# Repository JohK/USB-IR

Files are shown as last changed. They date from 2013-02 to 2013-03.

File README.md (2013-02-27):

Software
========
This software includes the firmware for a usb-to-IR sender dongle, the host cli interface for windows and linux and a labview programm for sending IR commands.

Other Software
==============
vusb
----
This package makes use of v-usb for avr, which can be used in the terms of GPL v2.

IRMP
----
IRMP is a package by Frank M. from the http://www.mikrocontroller.net/ web-board. The header also states a GPL license, a svn repository is over at mikrocontroller.net.

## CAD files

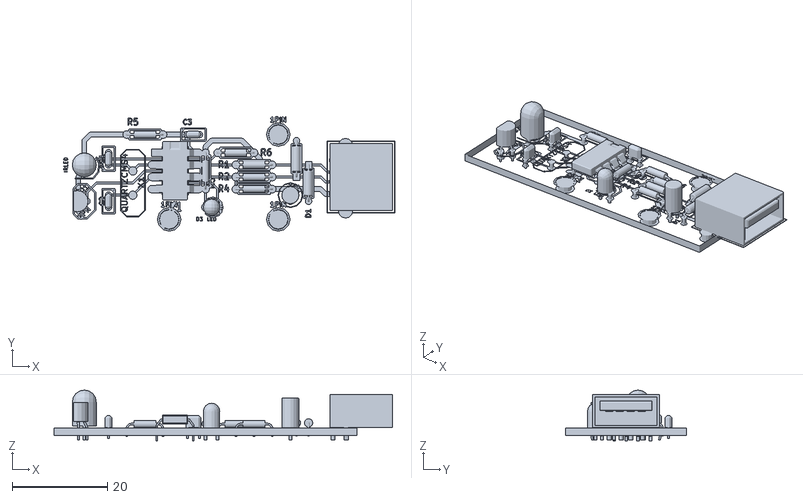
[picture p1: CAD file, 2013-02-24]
board/irusb.stl
71.4 x 25.4 x 10.7

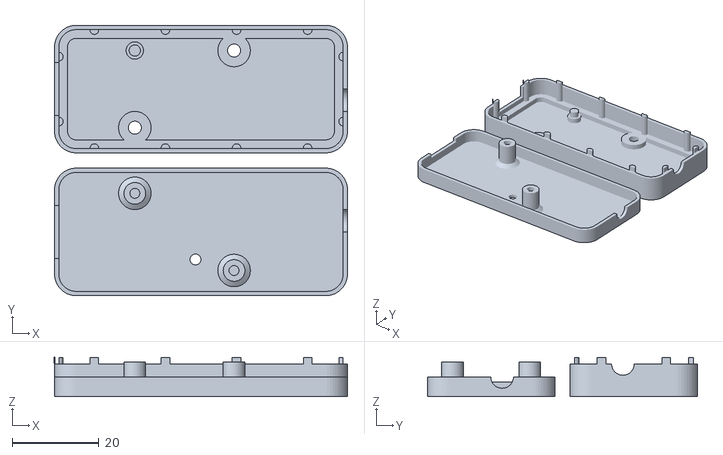
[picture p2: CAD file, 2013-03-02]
enclosing/irusb-enclosing.stl
67.5 x 62.3 x 9.00

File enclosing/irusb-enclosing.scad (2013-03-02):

$fn=50;

dim_brd = [63.5, 25.4, 10];
brd_thickness = 1.5;

brd_width = 25.4;
brd_length = 63.5;
brd_height = 10;

wall = 1;
wallv = [1,1,1];
cl_wall = 1;

o_width = brd_width+2*wall+2*cl_wall;
o_length = brd_length+2*wall+2*cl_wall;
o_height = brd_height+2*wall;

dimo = [o_length, o_width, o_height];
o_cornrad = 5;

// screw 1 x:-16.51  y: 3.81
pos_screw1 = [16.5, 21.59, 0];
// screw 2 x:-39.37  y: 3.81
pos_screw2 = [39.37, 21.59, 0];
// screw 3 x:-16.51  y:21.59
pos_screw3 = [16.51, 3.81, 0];

pos_irled = [dim_brd[0]+2*wallv[0]+0.5, 10.16, 5];
dia_irled = 5;
//y_irled = 15.24;
//z_irled = 7.5;

pos_sled = [30.48, 19.05, dim_brd[2]-2*wallv[2]];
dia_sled = 2;
//x_sled = -30.48;
//y_sled = 6.35;

pos_usb = [-3*wallv[0], dim_brd[1]/2, brd_thickness];
//y_usb = brd_width/2;


// include <nutsnbolts/cyl_head_bolt.scad>;


// board();


translate([0,0,wallv[2]+brd_thickness])  // manufact. offset

// bottom half
difference() {
	union() {
	//color("Grey", 0.2)
		case_rounded(dimo=dimo, wall=wallv, ch=7.5, cl=[2,2,1.5], r=o_cornrad, bottom=true, center=false);
	translate(pos_screw1) mountpost(ro = 2, ho = 1.5, ri = 1.5, hi = 1.75, cl_ri=0.2);

	translate(pos_screw2-[0,0,1.5]) cylinder(r=3.75,h=1.5);
	translate(pos_screw3-[0,0,1.5]) cylinder(r=3.75,h=1.5);
	}

	openings();
	translate(pos_screw2-[0,0,1.75])
		union() {
			cylinder(r=1.5,h=15,center=true);
			cylinder(r=2.75,h=2,center=true);
		}
	translate(pos_screw3-[0,0,1.75])
		union() {
			cylinder(r=1.5,h=15,center=true);
			cylinder(r=2.75,h=2,center=true);
		}


//translate([16.51,-50,-20]) cube([200,200,200]);
}


// upper half
 translate([0,-7.5,dimo[2]-wallv[2]-brd_thickness]) rotate ([180,0,0])
		
	difference(){
	union() {
		case_rounded(dimo=dimo, wall=wallv, ch=7.5, cl=[2,2,1.5], r=o_cornrad, bottom=false, center=false);
		for (pos_screw = [pos_screw2, pos_screw3]) {
			translate([0,0,dimo[2]-wallv[2]-cl_wall-brd_thickness]+pos_screw)
				rotate([180,0,0]) screwpost(do=5,di=2.3,h=7);
		}
	}

	openings();
	//translate(pos_screw2) cube(dimo);
}

module openings() {
	// ir-LED hole
	translate(pos_irled) rotate([0, -90, 0]) hole_led(d=dia_irled);
	// status LED hole
	translate(pos_sled) hole_led(d=2, cld=0.5);
	// usbA
	translate(pos_usb) hole_usbAm();
}













module case_rounded(
	dimo, // outer dimensions (vector)
	wall, // wall thicknesses (vector)
	r,    // corner radius
	ch,   // cut height (bottom, top)
	cl=[0.2, 0.2, 1], // board clearance
	bottom=true,
	center=true
 	) {

	translate(center ? [0,0,0] : dimo/2-wall-cl/2-[0,0,cl[2]/2])

	union() {

	difference(){
	union() {
		difference(){
			cube_rounded(dim=dimo,r=r,center=true);
			cube_rounded(dim=dimo-2*wall,r=r-wall[0],center=true);

			//translate([0,0,6]) cube([250,250,10], center=true);
		}

	// bevel
		translate([0,0,-dimo[2]/2+wall[2]+cl[2]/2])
		difference(){
			cube_rounded(dim=[dimo[0], dimo[1], cl[2]], r=r, center=true);
			assign(tmp = [dimo[0]-2*wall[0]-2*cl[0], dimo[1]-2*wall[1]-2*cl[1], cl[2]+0.1])
				cube_rounded(dim=tmp,r=r-wall[0]-cl[0],center=true);
		}
	} // end of union (basebody)

	translate(bottom ? [0,0, ch] : 
			            [0,0, -dimo[2]+ch])
		cube(dimo, center=true);
	}

	if (bottom) {
	// alignment
	difference() {
		for (i = [[-0.75, 1], [-0.25, 1], [0.25, 1], [0.75, 1],
                 [-0.75, -1], [-0.25, -1], [0.25, -1], [0.75, -1],
				  [-1, 0.55], [-1, -0.55],
                 [1, 0.55], [1, -0.55]]) {
			translate([i[0]*(dimo[0]/2-wall[0]),i[1]*(dimo[1]/2-wall[0]-0.1),-dimo[2]/2])
           		cylinder(d=wall[0],h=ch+1.5,center=false);
		}
			difference(){
			cube_rounded(dim=dimo,r=r,center=true);
			cube_rounded(dim=dimo-2*wall,r=r-wall[0],center=true);
		}
	}
	} // end if

	}
}







module mountpost( 
				   ro = 5,       // outer radius
                  ho = 1.5,     // height of post
                  ri = 3,       // radius of inner radius (that goes through mounting hole in pcb)
                  hi = 1.5,     // height of cyl that goes through mounting hole
                  cl_ri=0.2     // clearance for inner radius
                ) {
	translate([0, 0, -ho/2]) cylinder(r=ro, h=ho, center=true);
	translate([0, 0, hi/2]) cylinder(r=ri-cl_ri, h=hi, center=true);
	
}

module screwpost(
	di = 2.3,
	do = 5,
	h = 5,
	) {
	translate([0,0, h/2])
	difference() {
		union() {
			translate([0,0,-h/2+0.5]) cylinder(r1=do*.75, r2=do/2, h=1, center=true);
			cylinder(r=do/2,h=h,center=true); }
		cylinder(r=di/2,h=h+0.1,center=true);
	


	}
}


module board() {
	translate([0, brd_width, 0]) rotate([0, 0, 180]) 
	union() {
		color("DarkGreen") translate([-brd_length, 0, 0]) cube([brd_length, brd_width, 1.5]);
		translate([-24.75, 0, 0.7]) import_stl("../board/irusb.stl");
	}
}

module hole_led(d=5, h=5, cld=0.2) {
	translate([0,0, h/2]) cylinder(r=d/2+cld/2, h=h, center=true);
}

module hole_usbAm(l=15, clw=0.2, clh=0.2) {
	translate([l/2,0,(4.5+clh)/2]) cube([l,12+clw,4.5+clh], center=true);
}





module cube_rounded(
				dim=[1,1,1],  // dimension of "cube"
				r=0.5,          // radius of rounded corner (xy)
				center=false  // is centered?
					) {
	translate(center ? [0,0,0] : [dim[0]/2,dim[1]/2,0])
	hull() for(m=[[0,0,0], [1,0,0], [dim[0]-r*2,dim[1]-r*2,0], [0,1,0]])
		mirror(m) translate([dim[0]/2-r, dim[1]/2-r, 0]) cylinder(h=dim[2],r=r, center=center);
}


module square_rounded(l=60,w=25,h=10,r=5, center=false) {
	translate(center ? [0,0,0] : [l/2,w/2,0])
	hull() for(m=[[0,0,0], [1,0,0], [l-r*2,w-r*2,0], [0,1,0]])
		mirror(m) translate([l/2-r, w/2-r, 0]) cylinder(h=h,r=r, center=center);
}

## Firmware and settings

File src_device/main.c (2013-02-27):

/* Name: main.c
 * Project: hid-data, example how to use HID for data transfer
 * Author: Christian Starkjohann
 * Creation Date: 2008-04-11
 * Tabsize: 4
 * Copyright: (c) 2008 by OBJECTIVE DEVELOPMENT Software GmbH
 * License: GNU GPL v2 (see License.txt), GNU GPL v3 or proprietary (CommercialLicense.txt)
 * This Revision: $Id$
 */

/* PIN Configuration on Atmega 8
 *
 * Status LED:  PB0 (PIN14)
 * USB D-:		PD2 (PIN2)   // D-/D+ reversed for the usbSofCount feature
 * USB D+:		PD0 (PIN4)
 *
 */

/* PIN Configuration on ATtiny45
 # IR LED:	PB0 (PIN 5)
 # USB D-:  PB1 (PIN 6)
 # USB D+:  PB2 (PIN 7) 
*/

/*
This example should run on most AVRs with only little changes. No special
hardware resources except INT0 are used. You may have to change usbconfig.h for
different I/O pins for USB. Please note that USB D+ must be the INT0 pin, or
at least be connected to INT0 as well.
*/

#include <avr/io.h>
#include <avr/wdt.h>
#include <avr/interrupt.h>  /* for sei() */
#include <util/delay.h>     /* for _delay_ms() */
#include <avr/eeprom.h>

#include <avr/pgmspace.h>   /* required by usbdrv.h */
#include "usbdrv.h"
#include "oddebug.h"        /* This is also an example for using debug macros */

#include "irsnd.h"			/* IR Library */

/* ------------------------------------------------------------------------- */
/* ----------------------------- USB interface ----------------------------- */
/* ------------------------------------------------------------------------- */

PROGMEM const char usbHidReportDescriptor[22] = {    /* USB report descriptor */
    0x06, 0x00, 0xff,              // USAGE_PAGE (Generic Desktop)
    0x09, 0x01,                    // USAGE (Vendor Usage 1)
    0xa1, 0x01,                    // COLLECTION (Application)
    0x15, 0x00,                    //   LOGICAL_MINIMUM (0)
    0x26, 0xff, 0x00,              //   LOGICAL_MAXIMUM (255)
    0x75, 0x08,                    //   REPORT_SIZE (8)
    0x95, 0x06,                    //   REPORT_COUNT (6)
    0x09, 0x00,                    //   USAGE (Undefined)
    0xb2, 0x02, 0x01,              //   FEATURE (Data,Var,Abs,Buf)
    0xc0                           // END_COLLECTION
};


/* Since we define only one feature report, we don't use report-IDs (which
 * would be the first byte of the report). The entire report consists of 128
 * opaque data bytes.
 */

/* The following variables store the status of the current data transfer */
static uchar    currentAddress;
static uchar    bytesRemaining;

static uchar	buf[6];

static uchar	flag_send;



/* ------------------------------------------------------------------------- */

/* usbFunctionRead() is called when the host requests a chunk of data from
 * the device. For more information see the documentation in usbdrv/usbdrv.h.
 */
uchar   usbFunctionRead(uchar *data, uchar len)
{
    if(len > bytesRemaining)
        len = bytesRemaining;
    //eeprom_read_block(data, (uchar *)0 + currentAddress, len);

	//memcpy(data, &buf[currentAddress], len);
	*data = &buf;
    currentAddress += len;
    bytesRemaining -= len;
	flag_send = 1;
    return len;
}

/* usbFunctionWrite() is called when the host sends a chunk of data to the
 * device. For more information see the documentation in usbdrv/usbdrv.h.
 */
uchar   usbFunctionWrite(uchar *data, uchar len)
{
    if(bytesRemaining == 0)
        return 1;               /* end of transfer */
    if(len > bytesRemaining)
        len = bytesRemaining;
    //eeprom_write_block(data, (uchar *)0 + currentAddress, len);
	memcpy(&buf[currentAddress], data, len);
    currentAddress += len;
    bytesRemaining -= len;
	flag_send = 1;
    return bytesRemaining == 0; /* return 1 if this was the last chunk */
}

/* ------------------------------------------------------------------------- */

usbMsgLen_t usbFunctionSetup(uchar data[8])
{
usbRequest_t    *rq = (void *)data;

    if((rq->bmRequestType & USBRQ_TYPE_MASK) == USBRQ_TYPE_CLASS){    /* HID class request */
        if(rq->bRequest == USBRQ_HID_GET_REPORT){  /* wValue: ReportType (highbyte), ReportID (lowbyte) */
            /* since we have only one report type, we can ignore the report-ID */
            bytesRemaining = 6;
            currentAddress = 0;
            return USB_NO_MSG;  /* use usbFunctionRead() to obtain data */
        }else if(rq->bRequest == USBRQ_HID_SET_REPORT){
            /* since we have only one report type, we can ignore the report-ID */
            bytesRemaining = 6;
            currentAddress = 0;
            return USB_NO_MSG;  /* use usbFunctionWrite() to receive data from host */
        }
    }else{
        /* ignore vendor type requests, we don't use any */
    }
    return 0;
}

/* ------------------------------------------------------------------------- */

/*// start status LED, t blinking period in 
void statusLed_Start (uchar t)
{
	if (!Led_T) {
		Led_C = t;
		PORTB |= 0x01;	// LED off
	}
  Led_T = Led_F = t;
}

// LED-state  tested every 1 ms (SOF)
static void statusLed_On1ms(void) {
	uchar led_t = Led_T, led_c;
	if (!led_t) return;
		led_c = Led_C;			// load to register
	if (!--led_c) {
		PORTB ^= 0x01;			// toggle LED
		led_c = Led_F;			// reload counter
	}
 	if (!--led_t) PORTC &= ~0x01;	// switch LED on 
	Led_T = led_t;				// write back register
	Led_C = led_c;
}
*/


void timer1_init (void)
{
//#if defined (__AVR_ATtiny45__) || defined (__AVR_ATtiny85__)                // ATtiny45 / ATtiny85:
	
	// this is 266 ... for a 8bit timer this is too high
    //OCR1C   =  (F_CPU / F_INTERRUPTS / 4) - 1;                              // compare value: 1/15000 of CPU frequency, presc = 4
	OCR1C = 255;
    TCCR1   = (1 << CTC1) | (1 << CS11) | (1 << CS10);                      // switch CTC Mode on, set prescaler to 4
//#else                                                                       // ATmegaXX:
//    OCR1A   =  (F_CPU / F_INTERRUPTS) - 1;                                  // compare value: 1/15000 of CPU frequency
//    TCCR1B  = (1 << WGM12) | (1 << CS10);                                   // switch CTC Mode on, set prescaler to 1
//#endif

#ifdef TIMSK1
    TIMSK1  = 1 << OCIE1A;                                                  // OCIE1A: Interrupt by timer compare
#else
    TIMSK   = 1 << OCIE1A;                                                  // OCIE1A: Interrupt by timer compare
#endif
}



/*---------------------------------------------------------------------------------------------------------------------------------------------------
 *  * timer 1 compare handler, called every 1/10000 sec
 *   *---------------------------------------------------------------------------------------------------------------------------------------------------
 *    */
#if defined (__AVR_ATtiny45__) || defined (__AVR_ATtiny85__)                // ATtiny45 / ATtiny85:
	ISR(TIM1_COMPA_vect, ISR_NOBLOCK)
#else
	ISR(TIMER1_COMPA_vect, ISR_NOBLOCK)
#endif
{
	    (void) irsnd_ISR();                                                     // call irsnd ISR

		// call other timer interrupt routines here...
}



/* ------------------------------------------------------------------------- */

int main(void)
{
	//DDRB &= ~((1 << DDB1) | (1 << DDB2));
	//DDRB  = 0x01;
	//PORTB |= (1<<PB0); // LED IRLED debug
	uchar   i;
	//uchar SofCmp = 0;

	IRMP_DATA *irmp_data;

    wdt_enable(WDTO_1S);
    /* Even if you don't use the watchdog, turn it off here. On newer devices,
     * the status of the watchdog (on/off, period) is PRESERVED OVER RESET!
     */
    /* RESET status: all port bits are inputs without pull-up.
     * That's the way we need D+ and D-. Therefore we don't need any
     * additional hardware initialization.
     */
    //odDebugInit();
    //DBG1(0x00, 0, 0);       /* debug output: main starts */
    usbDeviceDisconnect();  /* enforce re-enumeration, do this while interrupts are disabled! */
    i = 0;
    while(--i){             /* fake USB disconnect for > 250 ms */
        wdt_reset();
        _delay_ms(1);
    }

	irsnd_init();			/* stuff */
	timer1_init();

    usbDeviceConnect();
    usbInit();
    sei();

    //DBG1(0x01, 0, 0);       /* debug output: main loop starts */

//DDRB |= (1 << DDB0); // debug

    for(;;){                /* main event loop */
        //DBG1(0x02, 0, 0);   /* debug output: main loop iterates */
        wdt_reset();
        usbPoll();

		// LED IRLED debug
		// PORTB=(1<<PB0);
		// _delay_ms(250);
//		 PORTB &= ~(1<<PB0);
		// _delay_ms(250);
		
		if (flag_send == 1) {
			flag_send = 0;
		//	irmp_data = (struct IRMP_DATA*) buf;
			IRMP_DATA    *irmp_data = (void *)buf;
        	irsnd_send_data (irmp_data, TRUE);

        //	irmp_data.protocol = IRMP_NEC_PROTOCOL;
        //	irmp_data.address  = 0x00FF;
        //	irmp_data.command  = 0x0001;
        //	irmp_data.flags    = 0;
		}



    }
    return 0;
}

/* ------------------------------------------------------------------------- */

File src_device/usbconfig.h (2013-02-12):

/* Name: usbconfig.h
 * Project: V-USB, virtual USB port for Atmel's(r) AVR(r) microcontrollers
 * Author: Christian Starkjohann
 * Creation Date: 2005-04-01
 * Tabsize: 4
 * Copyright: (c) 2005 by OBJECTIVE DEVELOPMENT Software GmbH
 * License: GNU GPL v2 (see License.txt), GNU GPL v3 or proprietary (CommercialLicense.txt)
 * This Revision: $Id$
 */

#ifndef __usbconfig_h_included__
#define __usbconfig_h_included__

/*
General Description:
This file is an example configuration (with inline documentation) for the USB
driver. It configures V-USB for USB D+ connected to Port D bit 2 (which is
also hardware interrupt 0 on many devices) and USB D- to Port D bit 4. You may
wire the lines to any other port, as long as D+ is also wired to INT0 (or any
other hardware interrupt, as long as it is the highest level interrupt, see
section at the end of this file).
+ To create your own usbconfig.h file, copy this file to your project's
+ firmware source directory) and rename it to "usbconfig.h".
+ Then edit it accordingly.
*/

/* ---------------------------- Hardware Config ---------------------------- */



#define USB_CFG_IOPORTNAME      B      // attiny
/* This is the port where the USB bus is connected. When you configure it to
 * "B", the registers PORTB, PINB and DDRB will be used.
 */
#define USB_CFG_DMINUS_BIT      1	// attiny
/* This is the bit number in USB_CFG_IOPORT where the USB D- line is connected.
 * This may be any bit in the port.
 */
#define USB_CFG_DPLUS_BIT       2	// attiny
/* This is the bit number in USB_CFG_IOPORT where the USB D+ line is connected.
 * This may be any bit in the port. Please note that D+ must also be connected
 * to interrupt pin INT0! [You can also use other interrupts, see section
 * "Optional MCU Description" below, or you can connect D- to the interrupt, as
 * it is required if you use the USB_COUNT_SOF feature. If you use D- for the
 * interrupt, the USB interrupt will also be triggered at Start-Of-Frame
 * markers every millisecond.]
 */
#define USB_CFG_CLOCK_KHZ       (F_CPU/1000)
/* Clock rate of the AVR in kHz. Legal values are 12000, 12800, 15000, 16000,
 * 16500, 18000 and 20000. The 12.8 MHz and 16.5 MHz versions of the code
 * require no crystal, they tolerate +/- 1% deviation from the nominal
 * frequency. All other rates require a precision of 2000 ppm and thus a
 * crystal!
 * Since F_CPU should be defined to your actual clock rate anyway, you should
 * not need to modify this setting.
 */
#define USB_CFG_CHECK_CRC       0
/* Define this to 1 if you want that the driver checks integrity of incoming
 * data packets (CRC checks). CRC checks cost quite a bit of code size and are
 * currently only available for 18 MHz crystal clock. You must choose
 * USB_CFG_CLOCK_KHZ = 18000 if you enable this option.
 */

/* ----------------------- Optional Hardware Config ------------------------ */

/* #define USB_CFG_PULLUP_IOPORTNAME   D */
/* If you connect the 1.5k pullup resistor from D- to a port pin instead of
 * V+, you can connect and disconnect the device from firmware by calling
 * the macros usbDeviceConnect() and usbDeviceDisconnect() (see usbdrv.h).
 * This constant defines the port on which the pullup resistor is connected.
 */
/* #define USB_CFG_PULLUP_BIT          4 */
/* This constant defines the bit number in USB_CFG_PULLUP_IOPORT (defined
 * above) where the 1.5k pullup resistor is connected. See description
 * above for details.
 */

/* --------------------------- Functional Range ---------------------------- */
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

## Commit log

2012-12-01 configuration of usb-device
2012-12-01 adapted hid report to correct length for IRSND
    [main.c]
2012-12-01 bugfix in usb config (pins)
    [usbconfig.h]
2012-12-02 added status led code
2012-12-03 sending data to usb device works
2012-12-03 irmpframe sent to device is forwarded via IR
2013-02-12 changes for attiny45 still does not work
    [main.c, usbconfig.h]
2013-02-14 fixed fuses, usb devices gets now listed by PC
    [main.c]
2013-02-15 added kicad files for board
    [irusb.brd, irusb.sch]
2013-02-24 Designed board with through hole components
    [irusb.brd, irusb.stl]
2013-02-24 started designing a 3d printable enclosing for the board
    [irusb-enclosing.scad]
2013-02-24 added missing base resistor for transistor in schematic
    [irusb.sch]
2013-02-27 still not working, wrong timer used?
    [main.c]
2013-02-27 timer1 is only 8bit in attiny45, compare value was 266
2013-03-02 implemendet cube_rounded(dim, r, center)
    [irusb-enclosing.scad]
2013-03-02 implemendet case_rounded(dim, wall, cl, r, center)
    [irusb-enclosing.scad]
2013-03-02 implemendet screwpost and divided case in upper and bottom half
    [irusb-enclosing.scad]
2013-03-02 first version of enclosure ready for printing
    [irusb-enclosing.scad, irusb-enclosing.stl]
